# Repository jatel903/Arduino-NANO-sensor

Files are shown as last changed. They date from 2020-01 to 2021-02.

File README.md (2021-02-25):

# Arduino NANO sensor board
## v1.0
###### jatel.sk

**Specification:**  
Power supply: 12V DC / 50mA  
Inputs: 2x analog with 1M pull-up resistor  
Output: 1x SPDT contact 0.5A / 125VAC  
Cover: [KM-18B](https://www.tme.eu/sk/details/km-18b/skatulky-pre-poplasne-zariad-a-senzory/maszczyk/km-18b-bk/)  
Programmer: [CH340 Serial Port Debugger USB to TTL Converter](https://www.aliexpress.com/item/32645188490.html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,searchweb201602_,searchweb201603_)  

  

**Description:**  
The electronic module was originally designed as  a staircase lighting switch. The module transforms the analog output from the [FSR](https://www.conrad.sk/senzor-tlaku-fsr-408.k503372) type pressure sensors into a two-state output with using of a relay.   

The output is a relay potential-free changeover contact 0.5A / 125VAC. The module is compatible with the Arduino nano 328 module, but does not include a USB converter. Therefore, it is necessary to use a standard Arduino USB [converter](https://www.aliexpress.com/item/32645188490.html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,searchweb201602_,searchweb201603_). The module contains a 3-pole DIP switch that can be used to set various program modes. The firmware for FSR sensor does not exist, but the firmware for the [automatic switch of pump for disinfectant liquid](https://github.com/jatel903/pwp12.git)  exists.

**The examples of other possibilities of use:**

* thermostat
* automatic lighting with PIR sensor
* alarm with PIR sensor or radar
* twilight switch
* logger
* automatic watering system
* fluid flow measurement and automatic switching according to the volume of fluid
* automatic switch of a pump for disinfectant liquid, etc  

**All mentioned applications above depend on the firmware, which you have to create yourself.**

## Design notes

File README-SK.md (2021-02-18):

# PRESEN-FSR
## v1.0
###### jatel.sk

**Špecifikácia:**  
Napájanie: 12V DC / 50mA  
Vstupy: 2x analógové s pull-up rezistorom 1M  
Výstup: 1x prepínací kontakt 0,5A/125VAC  
Kryt: [KM-18B](https://www.tme.eu/sk/details/km-18b/skatulky-pre-poplasne-zariad-a-senzory/maszczyk/km-18b-bk/)  
Programátor: [CH340 Serial Port Debugger USB to TTL Converter](https://www.aliexpress.com/item/32645188490.html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,searchweb201602_,searchweb201603_)

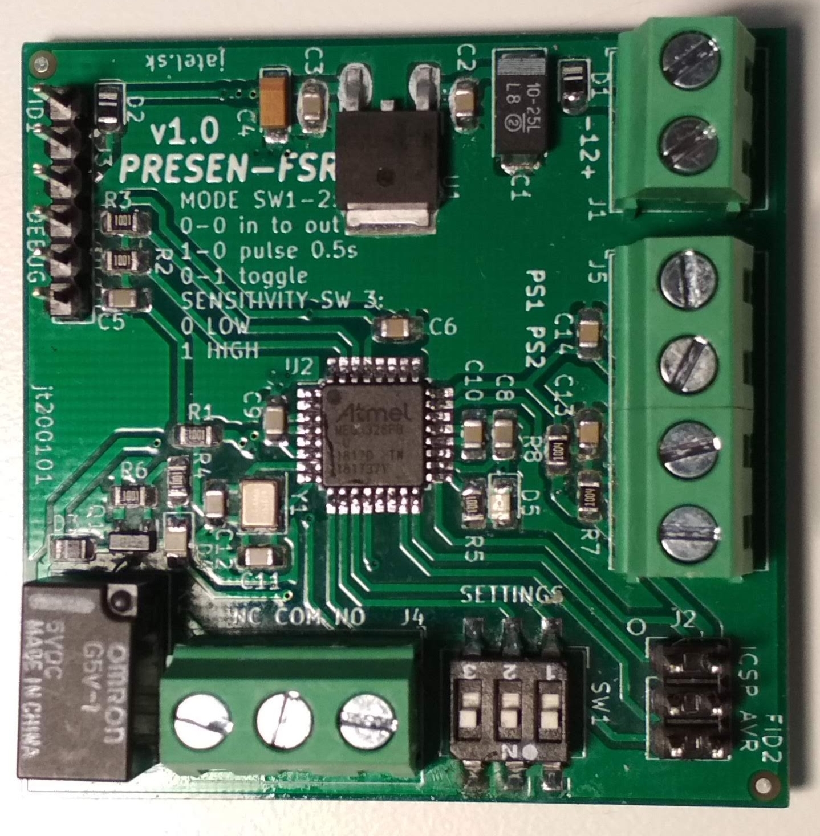
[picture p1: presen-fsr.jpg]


**Popis:**  
Elektronický modul pôvodne určený na pripojenie dvoch tlakových senzorov typu [FSR](https://www.conrad.sk/senzor-tlaku-fsr-408.k503372) od spoločnosti Interlink Electronics na dva analógové vstupy, ktoré mali byť umiestnené na schodisku ako spínač osvetlenia. Výstup je relátkový bezpotenciálový prepínací kontakt 0.5A/125VAC. Modul je kompatibilný s modulom Arduino nano 328, ale neobsahuje USB prevodník. Preto je potrebné použiť bežný Arduino USB [prevodník](https://www.aliexpress.com/item/32645188490.html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,searchweb201602_,searchweb201603_). Modul obsahuje 3-pólový DIP spínač, ktorý je možné použiť na nastavenie rôznych režimov programu. Možnosti použitia sú samozrejme širšie. Napr. sa môže na vstup pripojiť tepelné čidlo DS18B20 a modul môže slúžiť  ako termostat. Prípadne loger nejakých meraných veličín ako napr. teplota, vlhkosť, tlak, prietok kvapaliny a pod. Hodnoty by sa po meraní mohli vyčítať cez sériový port pomocou USB prevodníku. Všetko záleží od firmwaru.

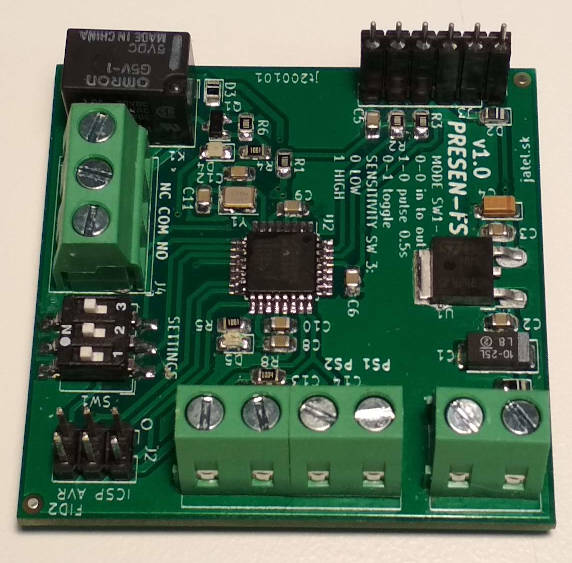
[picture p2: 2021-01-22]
pick and place/presen-fsr.jpg

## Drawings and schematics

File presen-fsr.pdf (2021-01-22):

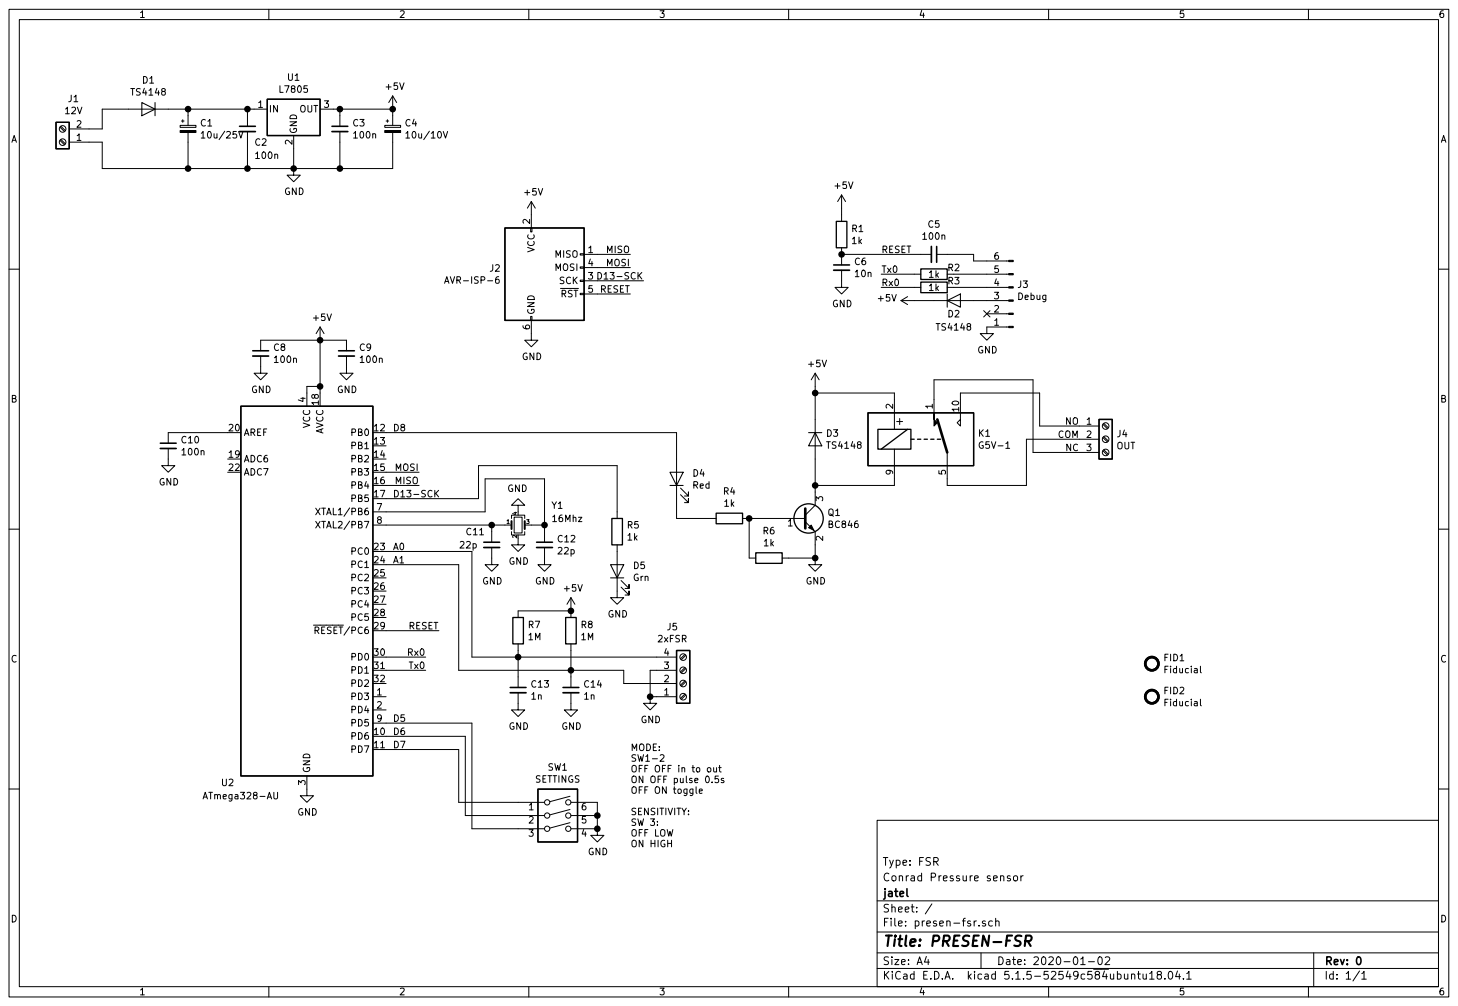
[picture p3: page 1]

OFF ON toggle SENSITIVITY: SW 3: OFF LOW

jatel Conrad Pressure sensor Type: FSR

File: presen-fsr.sch Sheet: /
Id: 1/1 Title: PRESEN-FSR

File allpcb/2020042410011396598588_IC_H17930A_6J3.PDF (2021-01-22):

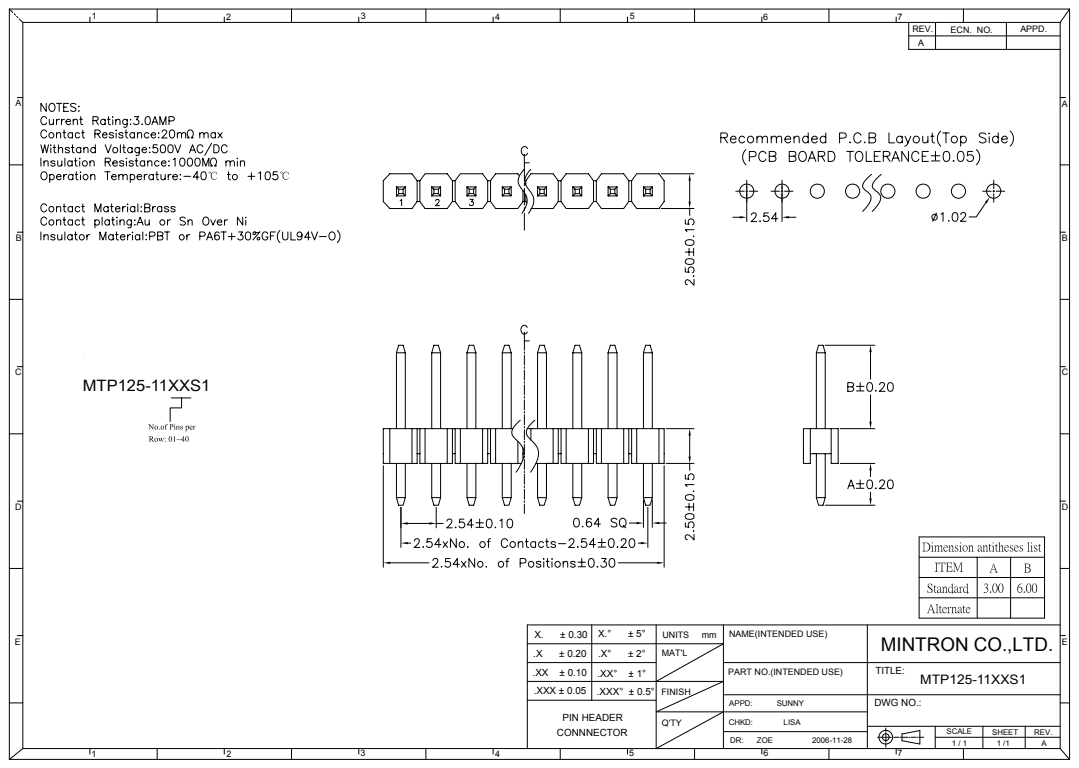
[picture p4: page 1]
PIN HEADER

REV. | ECN. NO. | APPD.

X. ± 0.30 | X.° ± 5° | UNITS mm | NAME(INTENDED USE) | MINTRON CO.,LTD.
.X ± 0.20 | .X° ± 2° | MAT'L
.XX ± 0.10 | .XX° ± 1° | | PART NO.(INTENDED USE) | TITLE: MTP125-11XXS1
.XXX ± 0.05 | .XXX° ± 0.5° | FINISH

APPD: SUNNY | DWG NO.:

Q'TY | CHKD: LISA

SCALE | SHEET | REV.
1 / 1 | 1 /1 | A

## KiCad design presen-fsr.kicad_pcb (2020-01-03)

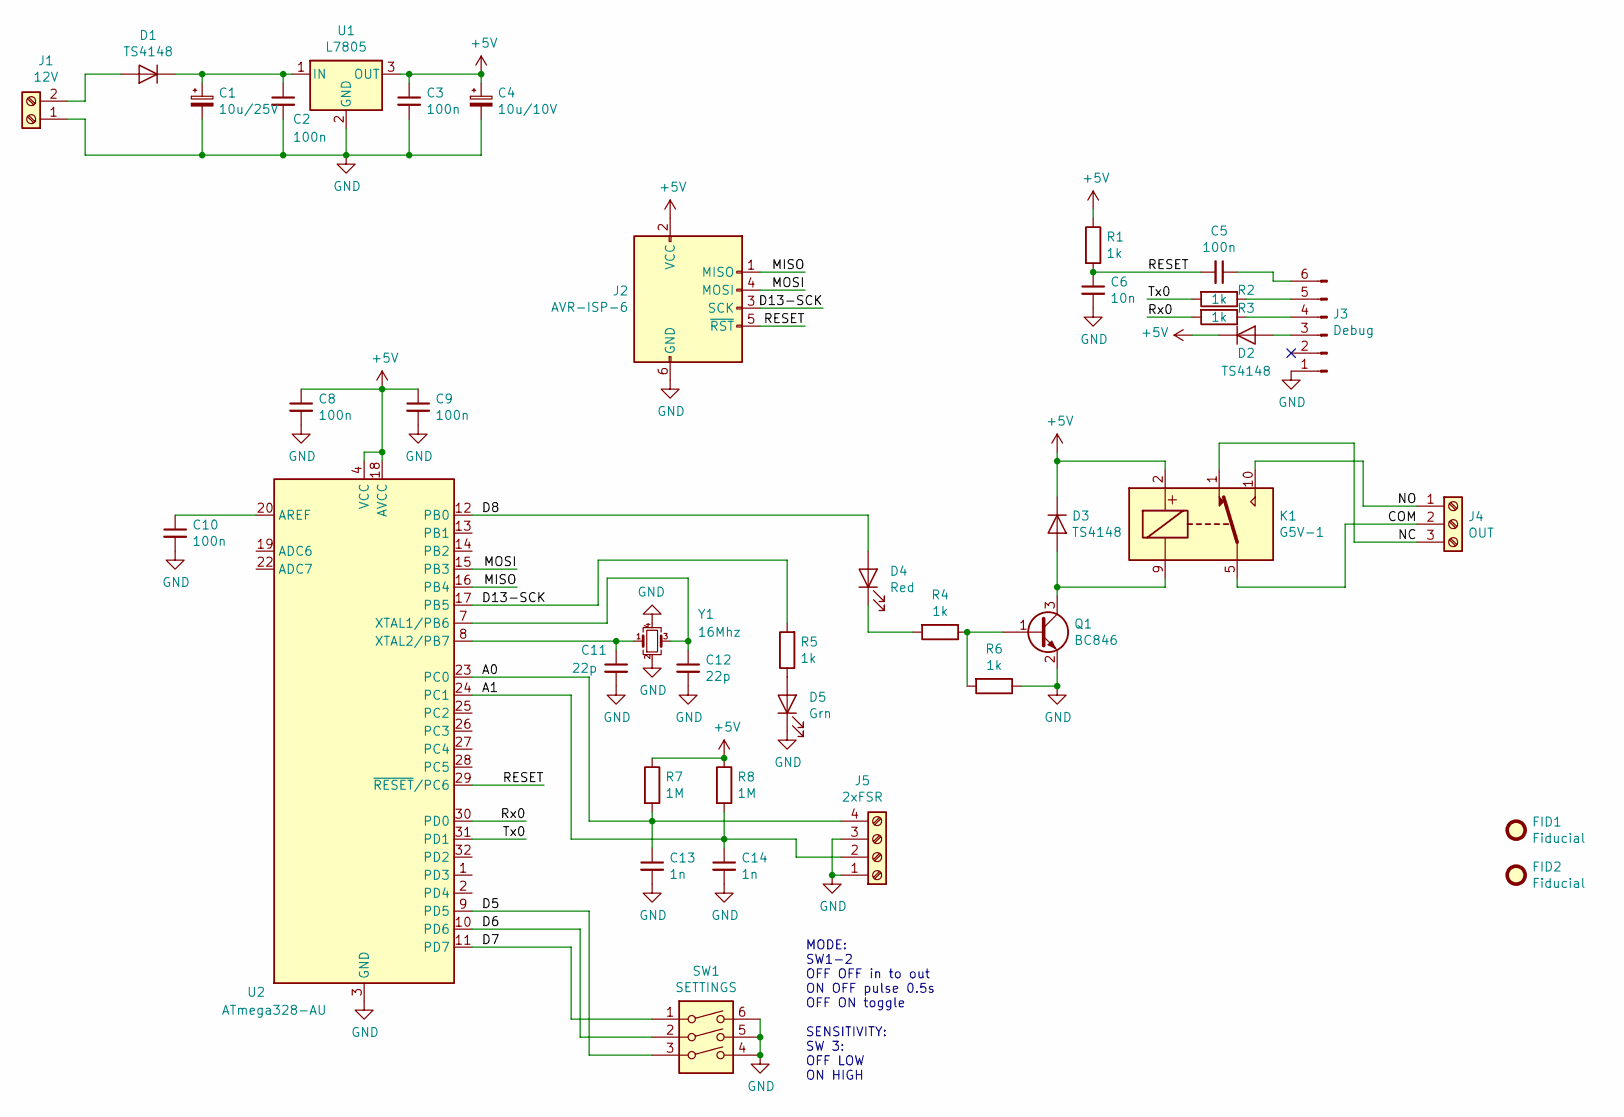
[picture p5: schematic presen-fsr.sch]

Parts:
C1: 10u/25V; CP_EIA-6032-20_AVX-F_Pad2.25x2.35mm_HandSolder
C2, C3, C5, C8, C9, C10: 100n; C_0805_2012Metric_Pad1.15x1.40mm_HandSolder
C4: 10u/10V; CP_EIA-3216-12_Kemet-S_Pad1.58x1.35mm_HandSolder
C6: 10n; C_0805_2012Metric_Pad1.15x1.40mm_HandSolder
C11, C12: 22p; C_0805_2012Metric_Pad1.15x1.40mm_HandSolder
C13, C14: 1n; C_0805_2012Metric_Pad1.15x1.40mm_HandSolder
D1, D2, D3: TS4148; D_0805_2012Metric
D4: Red; LED_0805_2012Metric_Pad1.15x1.40mm_HandSolder
D5: Grn; LED_0805_2012Metric_Pad1.15x1.40mm_HandSolder
FID1, FID2: Fiducial; Fiducial_1mm_Mask2mm
J1: 12V; TerminalBlock_Phoenix_MKDS-1,5-2-5.08_1x02_P5.08mm_Horizont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
J2: AVR-ISP-6; PinHeader_2x03_P2.54mm_Vertical
J3: Debug; PinHeader_1x06_P2.54mm_Vertical
J4: OUT; TerminalBlock_Phoenix_MKDS-1,5-3-5.08_1x03_P5.08mm_Horizont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
J5: 2xFSR; TerminalBlock_Phoenix_MKDS-1,5-4-5.08_1x04_P5.08mm_Horizont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
K1: G5V-1; Relay_SPDT_Omron_G5V-1
Q1: BC846; SOT-23
R1, R2, R3, R4, R5, R6: 1k; R_0805_2012Metric_Pad1.15x1.40mm_HandSolder
R7, R8: 1M; R_0805_2012Metric_Pad1.15x1.40mm_HandSolder
SW1: SETTINGS; SW_DIP_SPSTx03_Slide_6.7x9.18mm_W8.61mm_P2.54mm_LowProfile
U1: L7805; TO-252-2
U2: ATmega328-AU; TQFP-32_7x7mm_P0.8mm
Y1: 16Mhz; Crystal_SMD_3225-4Pin_3.2x2.5mm

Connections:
+5V: C3.1, C4.1, C8.1, C9.1, D2.1 (K), D3.1 (K), J2.2 (VCC), K1.2, R1.1, R7.1, R8.1, U1.3 (OUT), U2.4 (VCC), U2.6 (VCC), U2.18 (AVCC)
/A0: C13.1, J5.4, R7.2, U2.23 (PC0)
/A1: C14.1, J5.2, R8.2, U2.24 (PC1)
/COM: J4.2, K1.5, K1.6
/D5: SW1.3, U2.9 (PD5)
/D6: SW1.2, U2.10 (PD6)
/D7: SW1.1, U2.11 (PD7)
/D8: D4.2 (A), U2.12 (PB0)
/D13-SCK: J2.3 (SCK), R5.2, U2.17 (PB5)
/MISO: J2.1 (MISO), U2.16 (PB4)
/MOSI: J2.4 (MOSI), U2.15 (PB3)
/NC: J4.3, K1.1
/NO: J4.1, K1.10
/RESET: C5.2, C6.1, J2.5 (~RST), R1.2, U2.29 (~RESET~/PC6)
/Rx0: R3.2, U2.30 (PD0)
/Tx0: R2.2, U2.31 (PD1)
GND: C1.2, C2.2, C3.2, C4.2, C6.2, C8.2, C9.2, C10.2, C11.2, C12.2, C13.2, C14.2, D5.1 (K), J1.1, J2.6 (GND), J3.1, J5.1, J5.3, Q1.2 (E), R6.1, SW1.4, SW1.5, SW1.6, U1.2 (GND), U2.3 (GND), U2.5 (GND), U2.21 (GND), Y1.2, Y1.4
unnamed: C1.1, C2.1, D1.1 (K), U1.1 (IN)
unnamed: C5.1, J3.6
unnamed: C10.1, U2.20 (AREF)
unnamed: C11.1, U2.8 (XTAL2/PB7), Y1.1
unnamed: C12.1, U2.7 (XTAL1/PB6), Y1.3
unnamed: D1.2 (A), J1.2
unnamed: D2.2 (A), J3.3
unnamed: D3.2 (A), K1.9, Q1.3 (C)
unnamed: D4.1 (K), R4.2
unnamed: D5.2 (A), R5.1
unnamed: J3.4, R3.1
unnamed: J3.5, R2.1
unnamed: Q1.1 (B), R4.1, R6.2

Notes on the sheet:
MODE: SW1-2 OFF OFF in to out ON OFF pulse 0.5s OFF ON toggle SENSITIVITY: SW 3: OFF LOW ON HIGH

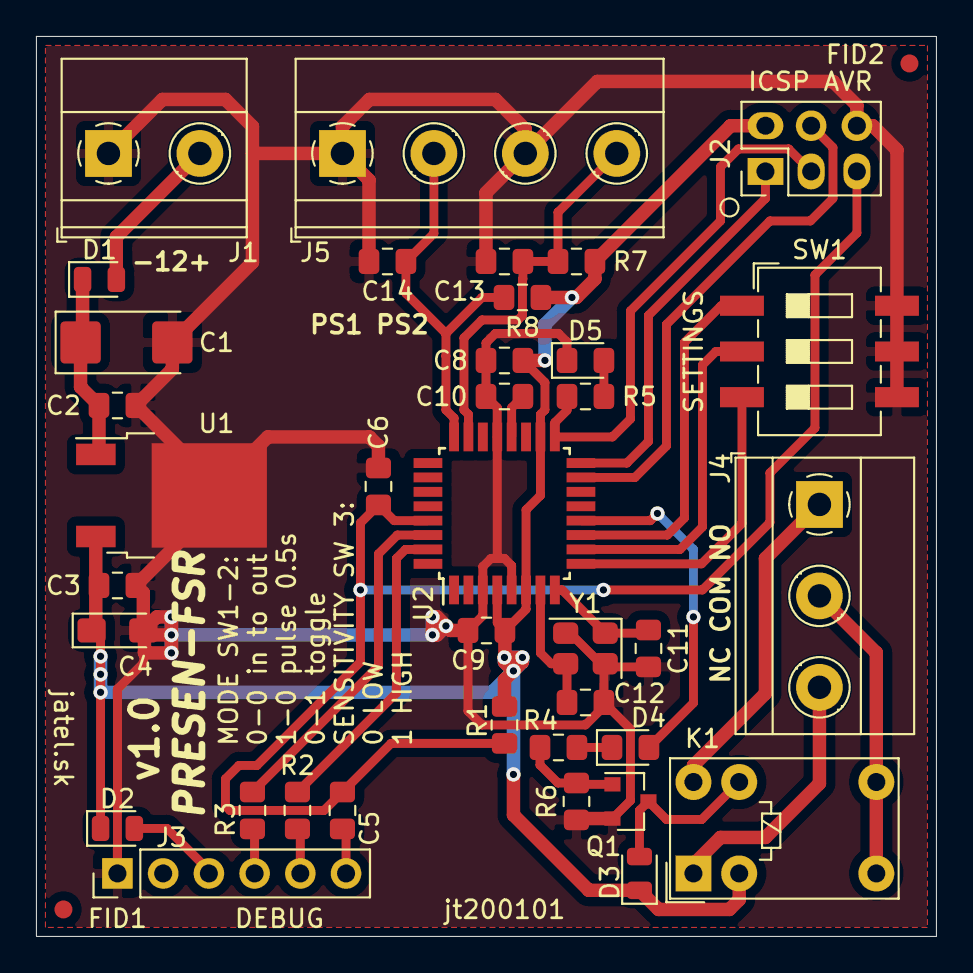
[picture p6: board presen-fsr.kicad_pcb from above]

Board: 2 copper layers, 50.0 x 50.0 mm, 39 parts (0 on the bottom side), 30 nets.
